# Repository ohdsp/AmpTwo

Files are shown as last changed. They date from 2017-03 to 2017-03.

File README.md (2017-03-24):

# [Open Hardware DSP Platform](http://www.ohdsp.org)
## AmpTwo
### Revision 1.0

---
# README
### Disclaimer
Copyright Paul Janicki 2017

Licensed under the TAPR Open Hardware License (www.tapr.org/OHL)

This documentation is distributed WITHOUT ANY EXPRESS OR IMPLIED WARRANTY, INCLUDING OF MERCHANTABILITY, SATISFACTORY QUALITY AND FITNESS FOR A PARTICULAR PURPOSE.

### What is this repository?

**Quick summary**

This is Open Hardware DSP Platform AmpTwo Module. 

This is a dual independant stereo headphone amplifier with analogue volume control. All 4 channels are fed from different DAC outputs from the ADAU1966 DAC module.

This repository contains the KiCad design files, manufacturing Gerber/drill files, PDF/drawing files, and relevant documenation for this board.

### What is the project folder structure?
Most folder names are self explanatory. Starting from the top level: \
*AmpTwo*
+ *Bill of Materials*  - This contains the bill of materials in CVS, LibreOffice Calc and XML formats
+ *Drawings*  - This contains PDF and SVG outputs of schematic and PCB files
+ *Gerbers* - This contains the PCB Gerbers and drill drawings for manufacture, there is also a zip file ready to send to most manufacturers
+ *KiCad* - This contains the original KiCad schematic and PCB design files
+ *Pick-Place and Stencil* - This contains the pick and place file for automated placement of PCB components and the pasate/stencil layer to make a solder paste stencil 

### How do I get set up?

**Summary of set up**

1. Set your self up a directory on a local disk, something simple will make life easier (eg C:\Electronics on Windows as used here), but anywhere will do just fine.
2. Download the Kicad-Libs from [https://github.com/ohdsp/KiCad-Libs](https://github.com/ohdsp/KiCad-Libs) and place in C:\Electronics\Kicad-Libs (or your chosen folder) 
3. Create a OHDSP subdirectory in C:\Electronics (so C:\Electronics\OHDSP)
3. Download this project to C:\Electronics\OHDSP\AmpTwo
4. Fire up Kicad
5. Open the main project file C:\Electronics\OHDSP\AmpTwo\KiCad\AmpTwo.pro
6. (Optional) Setup Pcbnew component library as below.
7. Do as you wish with the project, just keep it under TAPR Open Hardware License

Make sure your git setup doesn't exclude files used in the project (like .LIB files) or things may go wrong down the line.

**KiCad Library Configuration**

Note that you need to setup a Pcbnew library, but the eeschema libraries should work without any changes if you followed the instructions above.

To setup Pcbnew libraries:

In Pcbnew go to Preferences -> Footprint Libraries Manager. Under Global Libraries tab in the top list check if there is a nickname "MyKiCadLibs-Footprints" (usually at the end of the list). If there is but it points to the wrong place then change the Library Path to point to MyKiCadLibs-Footprints (eg C:\Electronics\KiCad-Libs\MyKiCadLibs-Footprints.pretty) folder for your setup. If this is missing you can use "Append with Wizard", choose "Files on my computer", click next, browse to library location (eg C:\Electronics\KiCad-Libs\MyKiCadLibs-Footprints.pretty) and select the folder MyKiCadLibs-Footprints.pretty, click next, check the Status column states OK and the Format is KiCad (if not re-download the library) and click next, then select "To global library configuration..." and click Finish.

To setup eeschema component libraries:
Either from KiCad project window go to Tools -> Run Library Editor OR under eeschema, go to Tools -> Library Editor. Then Preferences -> Component Libraries.

The top section "Component Library Files" should ideally contain only two libraries, the "power" library that ships with KiCad and "MyKiCadLibs-Lib" available from above. To setup MyKiCadLibs-Lib as a relative path under the "User defined search path" click add. Browse to the location of KiCad-Libs you download above (eg C:\Electronics\KiCad-Libs) and click "Select Folder". Say yes to add a relative path. Under component library files click add, browse to the KiCad-libs again (eg C:\Electronics\KiCad-Libs), select file "MyKiCadLibs-Lib.lib" and click open. MyKiCadLibs-lib should appear in the component library list with no path as it will be using the user defined search path set in the box below.

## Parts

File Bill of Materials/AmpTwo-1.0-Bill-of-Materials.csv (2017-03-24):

Reference | Quantity | Footprint | Value | Description | Voltage | Type | Tolerance | Size | Power
C101 C103 C201 C231 C301 C303 | 6 | CAP-TH-D8mmP3.5mm | 220u | 'Aluminium electrolytic capacitor | '35V | ' | ' | 'Pitch 3.5mm, Diameter 8mm | '
C102 C104 C202 C232 C302 C304 C314 C316 | 8 | SMD-0805 | 100n | 'Ceramic capacitor | '50V | 'X7R | '10% | '0805 | '
C204 C205 C211 C212 C218 C219 C225 C226 | 8 | CAP-TH-D8mmP3.5mm | 100u | 'High quality capacitor, eg Panasonic FC | '35V | ' | ' | 'Pitch 3.5mm, Diameter 8mm | '
C203 C206 C207 C210 C213 C214 C217 C220 C221 C224 C227 C228 | 12 | SMD-0805 | 1n | 'Ceramic capacitor | '50V | 'C0G | '5% | '0805 | '
C208 C209 C215 C216 C222 C223 C229 C230 C309 C310 C321 C322 | 12 | CAP_TH_5mm_W3.5mm | 100n | 'Polyester film capacitor | '63V | 'MKT | '5% | '5mm | '
C305 C306 C307 C308 C317 C318 C319 C320 | 8 | SMD-0805 | 220p | 'Ceramic capacitor | '50V | 'C0G | '5% | '0805 | '
C311 C312 C323 C324 | 4 | CAP-TH-D8mmP3.5mm | 220u | 'High quality capacitor, eg Panasonic FC | '35V | ' | ' | 'Pitch 3.5mm, Diameter 8mm | '
CN301 CN302 | 2 | CON-6.35mm-ACJS-MHDR-FCR11155 | CONN_6.35mm_SW_FCR11155_ACJS-MHDR | '6.35mm PCB Mount Jack - Examples Cliff FCR11155 or AMPHENOL ACJS-MHDR | ' | ' | ' | ' | '
D301 D302 D303 D304 D305 D306 D307 D308 | 8 | DIODE-SOD-123 | 1N4148W | 'Any 1N4148 SOD-123 Diode | ' | ' | ' | ' | '
P101 P102 | 2 | CONN-SCREW-2WAY-7.5mm-7.62mm | CONN_2x1 | '7.5mm or 7.62mm pitch 2 way screw terminal | ' | ' | ' | ' | '
P201 | 1 | CONN_DIL_2X10_BOX_1MM | CONN_02X10 | '2x10 2.54mm pitch box header | ' | ' | ' | ' | '
R202 R208 R211 R218 R221 R228 R231 R238 | 8 | SMD-1206 | 1k3 | 'MELF0204 or 1206 | ' | ' | '1% | '1206 | '250mW
R204 R209 R214 R219 R224 R229 R234 R239 | 8 | SMD-1206 | 1k5 | 'MELF0204 or 1206 | ' | ' | '1% | '1206 | '250mW
R212 R222 R232 R240 | 4 | SMD-1206 | 22k | 'MELF0204 or 1206 | ' | ' | '1% | '1206 | '250mW
R203 R206 R213 R216 R223 R226 R233 R236 | 8 | SMD-1206 | 100k | 'MELF0204 or 1206 | ' | ' | '1% | '1206 | '250mW
R201 R205 R207 R210 R215 R217 R220 R225 R227 R230 R235 R237 | 12 | SMD-1206 | 100 | 'MELF0204 or 1206 | ' | ' | '1% | '1206 | '250mW
R301 R302 R321 R322 R323 R324 R343 R344 | 8 | SMD-1206 | 4k7 | 'MELF0204 or 1206 | ' | ' | '1% | '1206 | '250mW
R303 R304 R305 R306 R313 R314 R315 R316 R317 R318 R325 R326 R327 R328 R335 R336 R337 R338 R339 R340 | 20 | SMD-1206 | 10 | 'MELF0204 or 1206 | ' | ' | '1% | '1206 | '250mW
R307 R308 R309 R310 R311 R312 R319 R320 R329 R330 R331 R332 R333 R334 R341 R342 | 16 | SMD-1206 | 10k | 'MELF0204 or 1206 | ' | ' | '1% | '1206 | '250mW
TR301 TR302 TR305 TR306 | 4 | IC-SOT-223 | BCP56-16 | 'NPN Transistor | '80V | '1A |  |  | '1.5W
TR303 TR304 TR307 TR308 | 4 | IC-SOT-223 | BCP53-16 | 'PNP Transistor | '80V | '1A |  |  | '1.5W
U201 U202 | 2 | IC_SOIC_8 | TLE2082 | Any high quality dual op-amp | '36V
U301 U302 U303 U304 | 4 | IC_SOIC_8 | TLE2081 | Any high quality single op-amp | '36V
VR201 VR202 | 2 | POT_DUAL_16mm_17mm_20mm | 100k | 'Any 16mm, 17mm or 20mm linear dual gang potentiometer | ' | ' | 20% | ' | '

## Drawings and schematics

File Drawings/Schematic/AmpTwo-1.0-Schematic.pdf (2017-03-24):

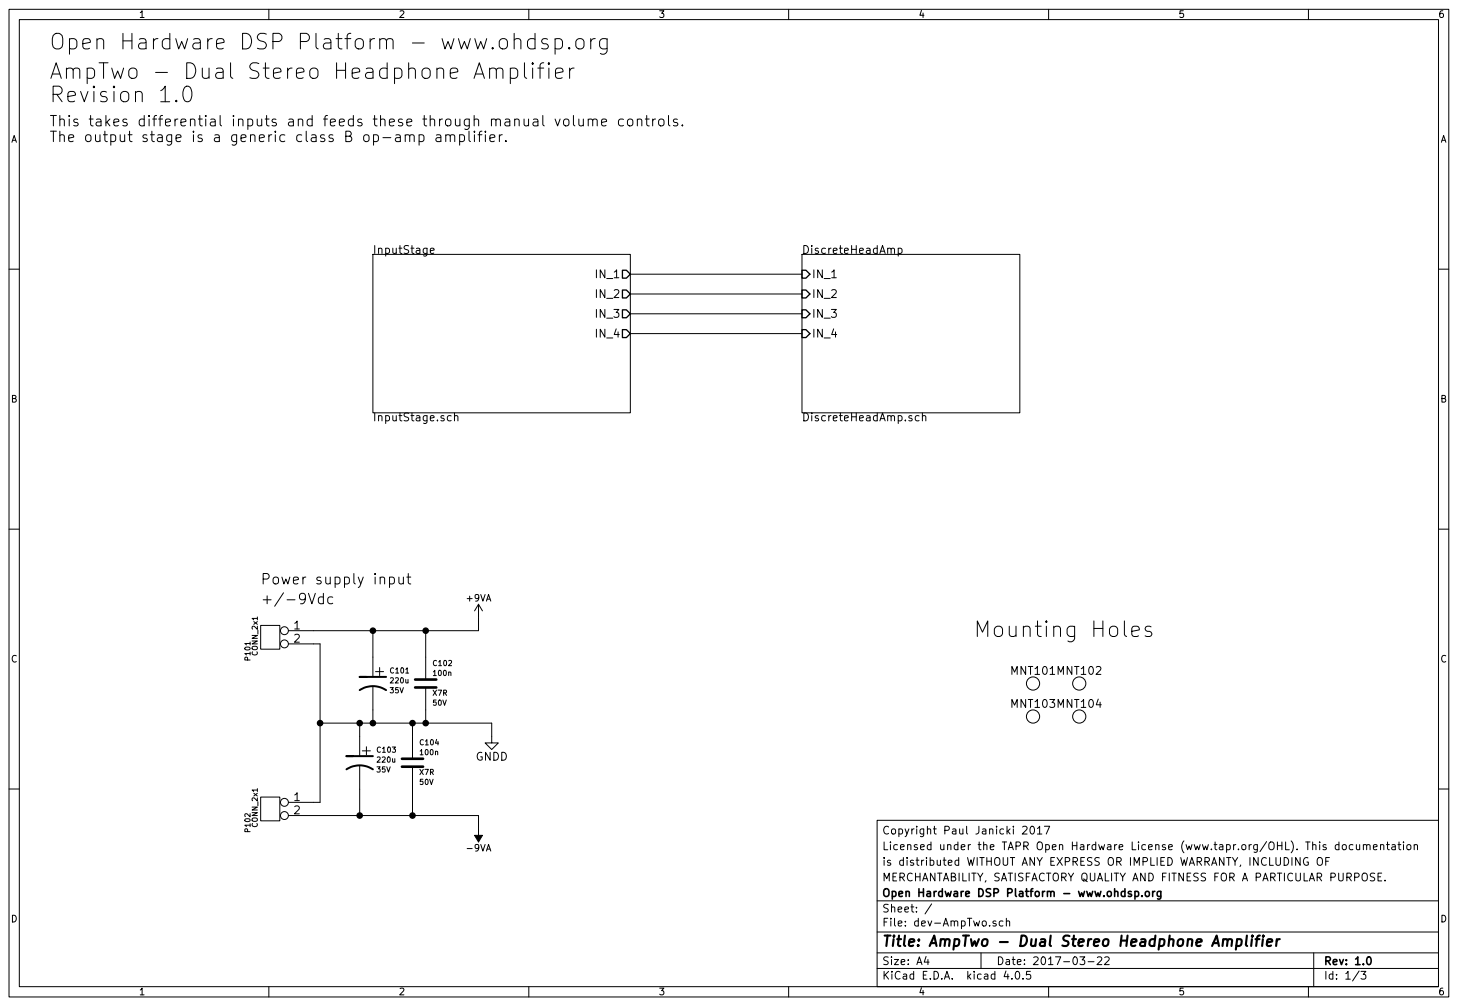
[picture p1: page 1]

Open Hardware DSP Platform - www.ohdsp.org
AmpTwo - Dual Stereo Headphone Amplifier
Revision 1.0
This takes differential inputs and feeds these through manual volume controls.
The output stage is a generic class B op-amp amplifier.

Copyright Paul Janicki 2017
Licensed under the TAPR Open Hardware License (www.tapr.org/OHL). This documentation
is distributed WITHOUT ANY EXPRESS OR IMPLIED WARRANTY, INCLUDING OF
MERCHANTABILITY, SATISFACTORY QUALITY AND FITNESS FOR A PARTICULAR PURPOSE.
File: dev-AmpTwo.sch Sheet: / Open Hardware DSP Platform - www.ohdsp.org

Id: 1/3 Title: AmpTwo - Dual Stereo Headphone Amplifier

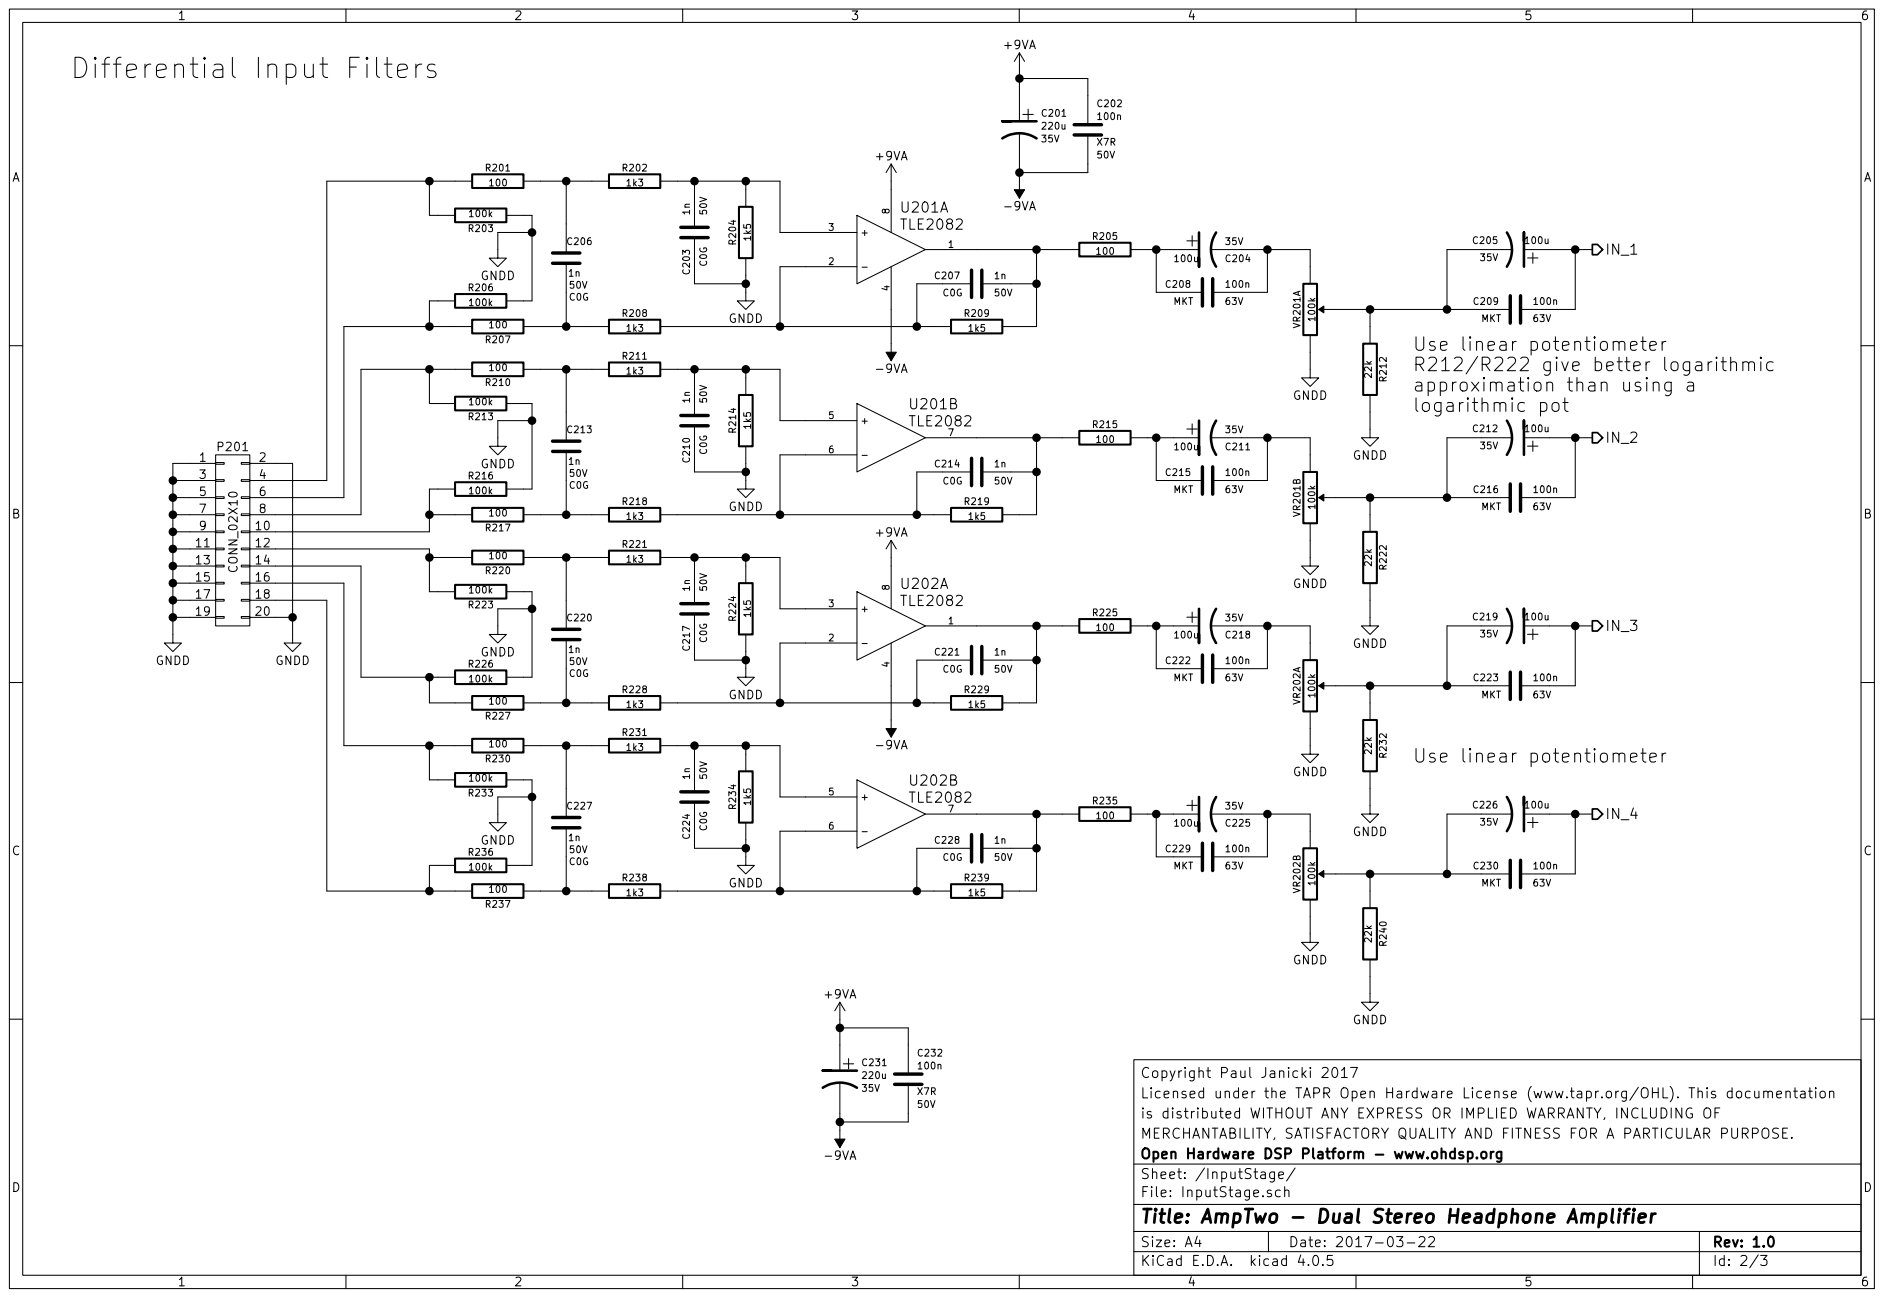
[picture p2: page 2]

11 | 12
13 | 14
15 | 16
17 | 18

Copyright Paul Janicki 2017
Licensed under the TAPR Open Hardware License (www.tapr.org/OHL). This documentation
is distributed WITHOUT ANY EXPRESS OR IMPLIED WARRANTY, INCLUDING OF
MERCHANTABILITY, SATISFACTORY QUALITY AND FITNESS FOR A PARTICULAR PURPOSE.
Open Hardware DSP Platform - www.ohdsp.org
Sheet: /InputStage/
File: InputStage.sch
Id: 2/3 Title: AmpTwo - Dual Stereo Headphone Amplifier

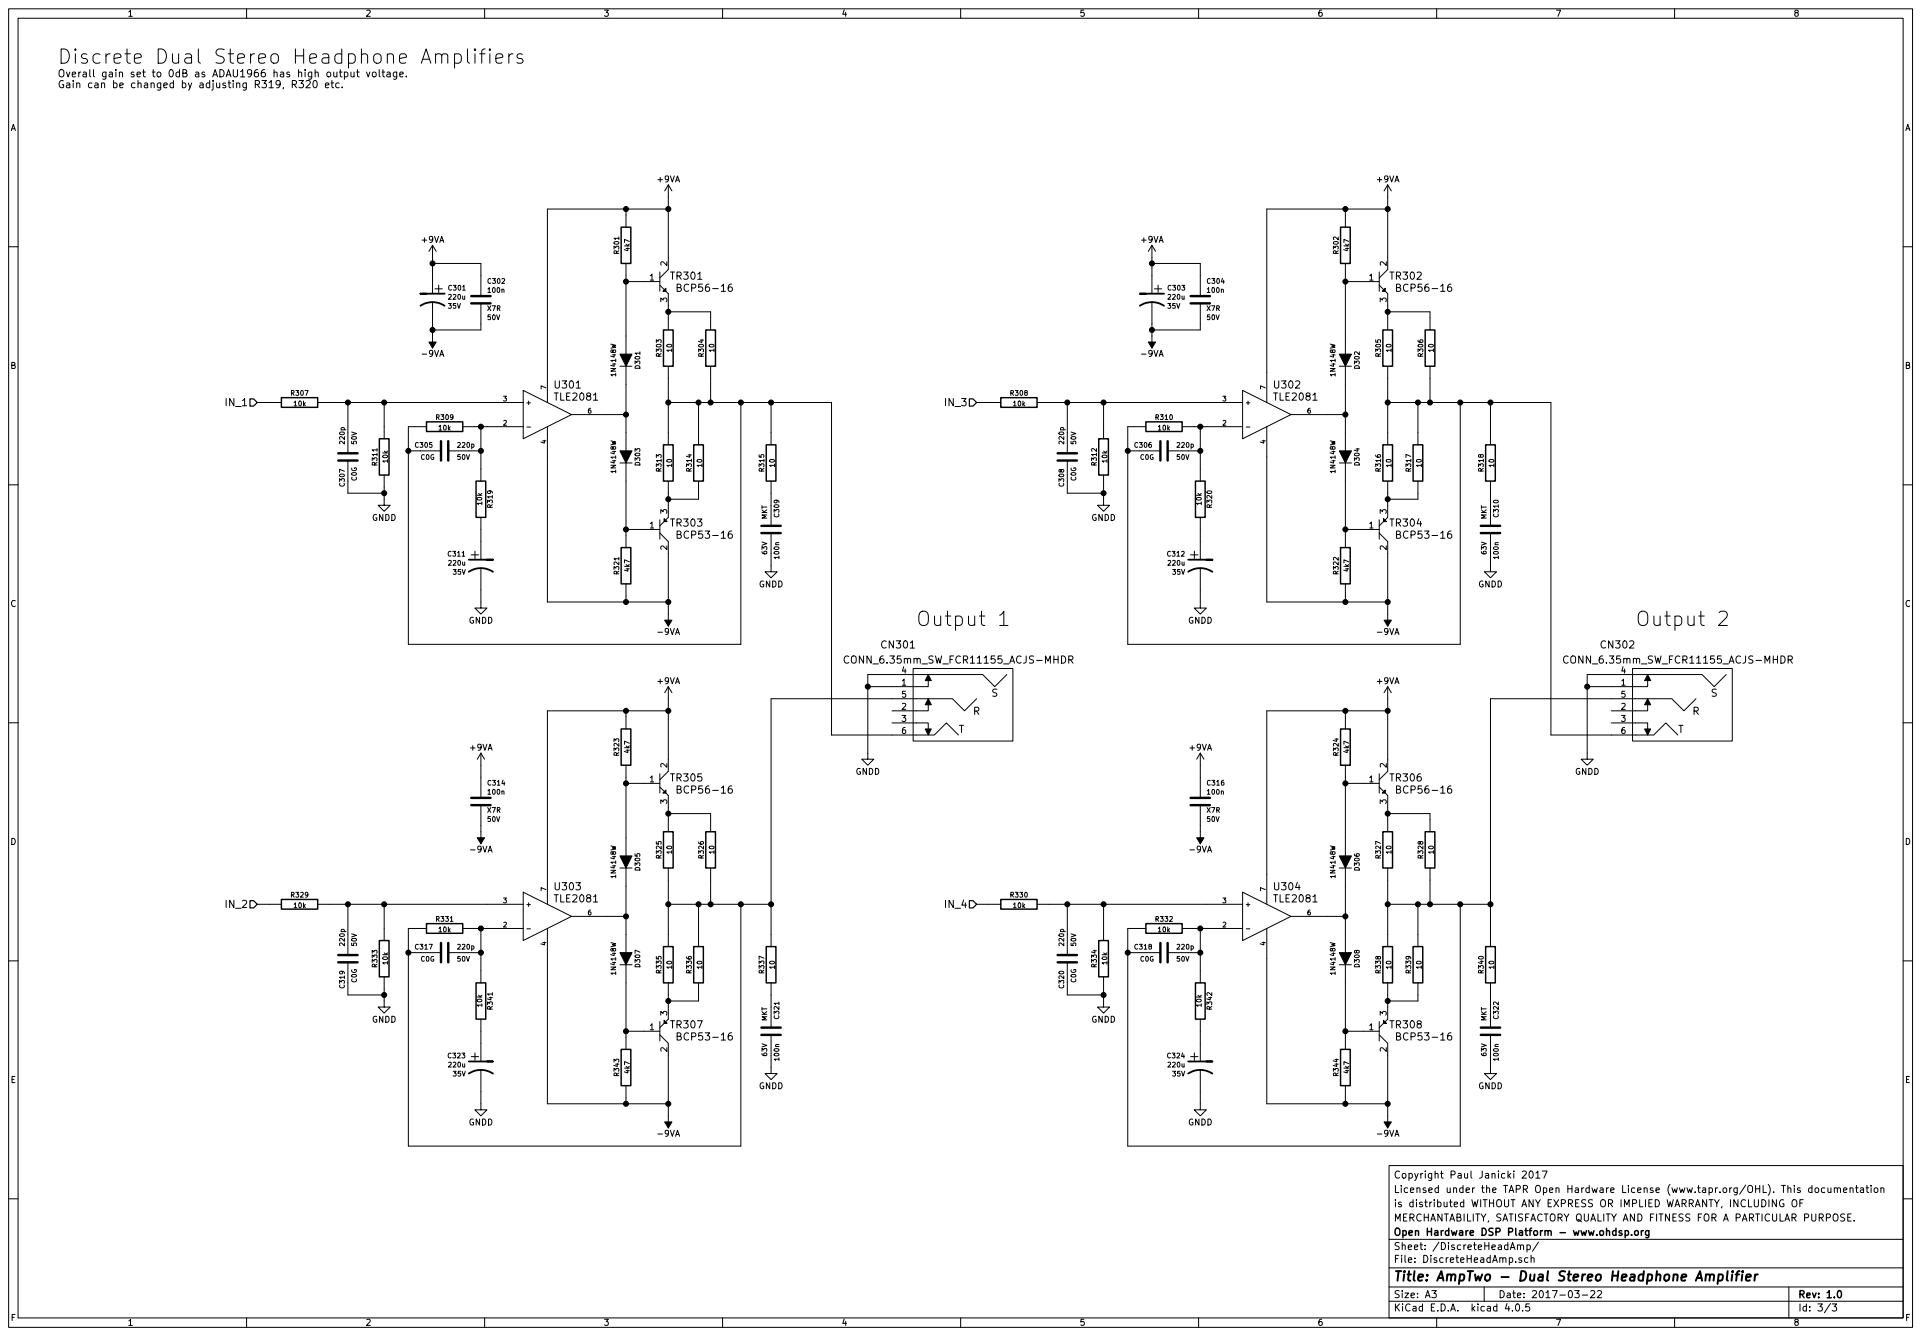
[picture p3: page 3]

Discrete Dual Stereo Headphone Amplifiers

Overall gain set to 0dB as ADAU1966 has high output voltage.
Gain can be changed by adjusting R319, R320 etc.

Copyright Paul Janicki 2017
Licensed under the TAPR Open Hardware License (www.tapr.org/OHL). This documentation
is distributed WITHOUT ANY EXPRESS OR IMPLIED WARRANTY, INCLUDING OF
MERCHANTABILITY, SATISFACTORY QUALITY AND FITNESS FOR A PARTICULAR PURPOSE.
Open Hardware DSP Platform - www.ohdsp.org
Sheet: /DiscreteHeadAmp/
File: DiscreteHeadAmp.sch
Id: 3/3 Title: AmpTwo - Dual Stereo Headphone Amplifier

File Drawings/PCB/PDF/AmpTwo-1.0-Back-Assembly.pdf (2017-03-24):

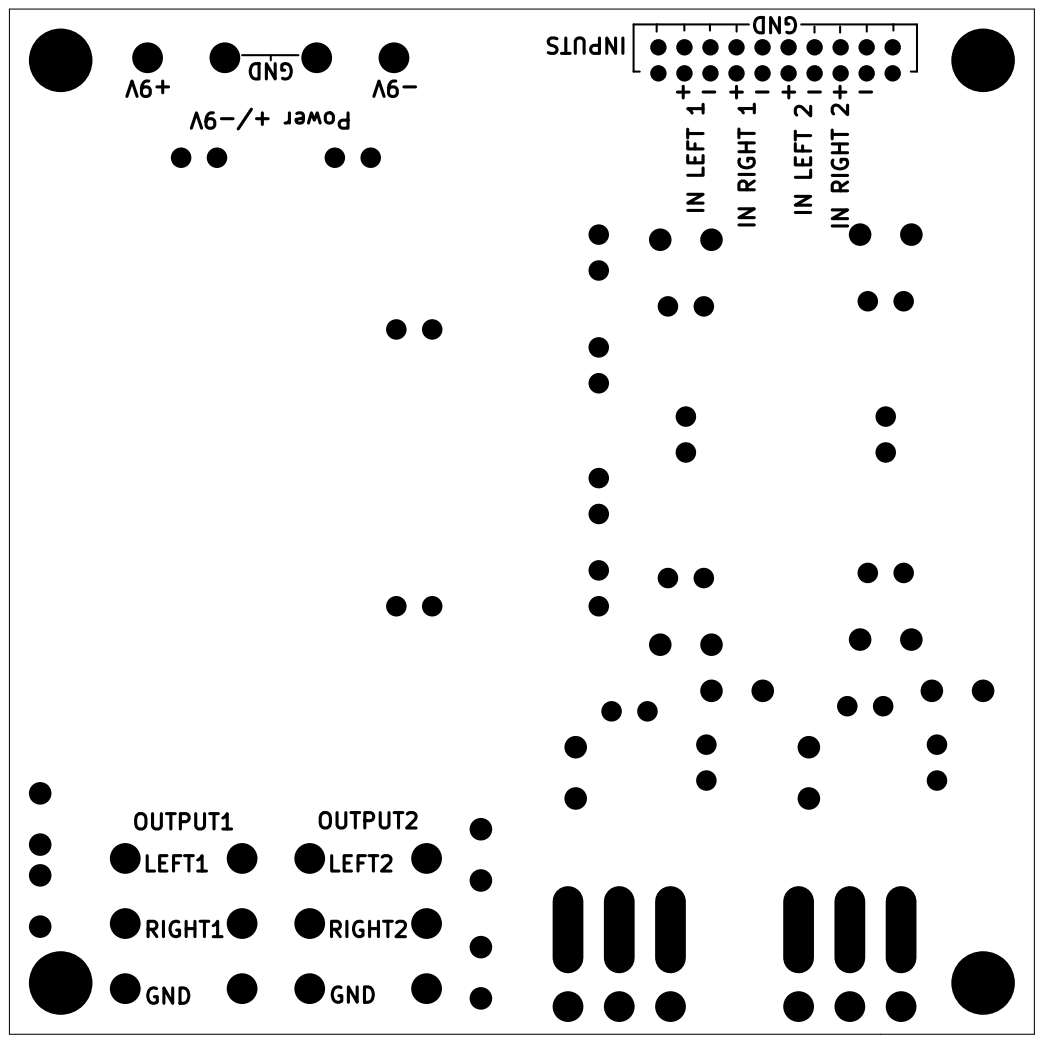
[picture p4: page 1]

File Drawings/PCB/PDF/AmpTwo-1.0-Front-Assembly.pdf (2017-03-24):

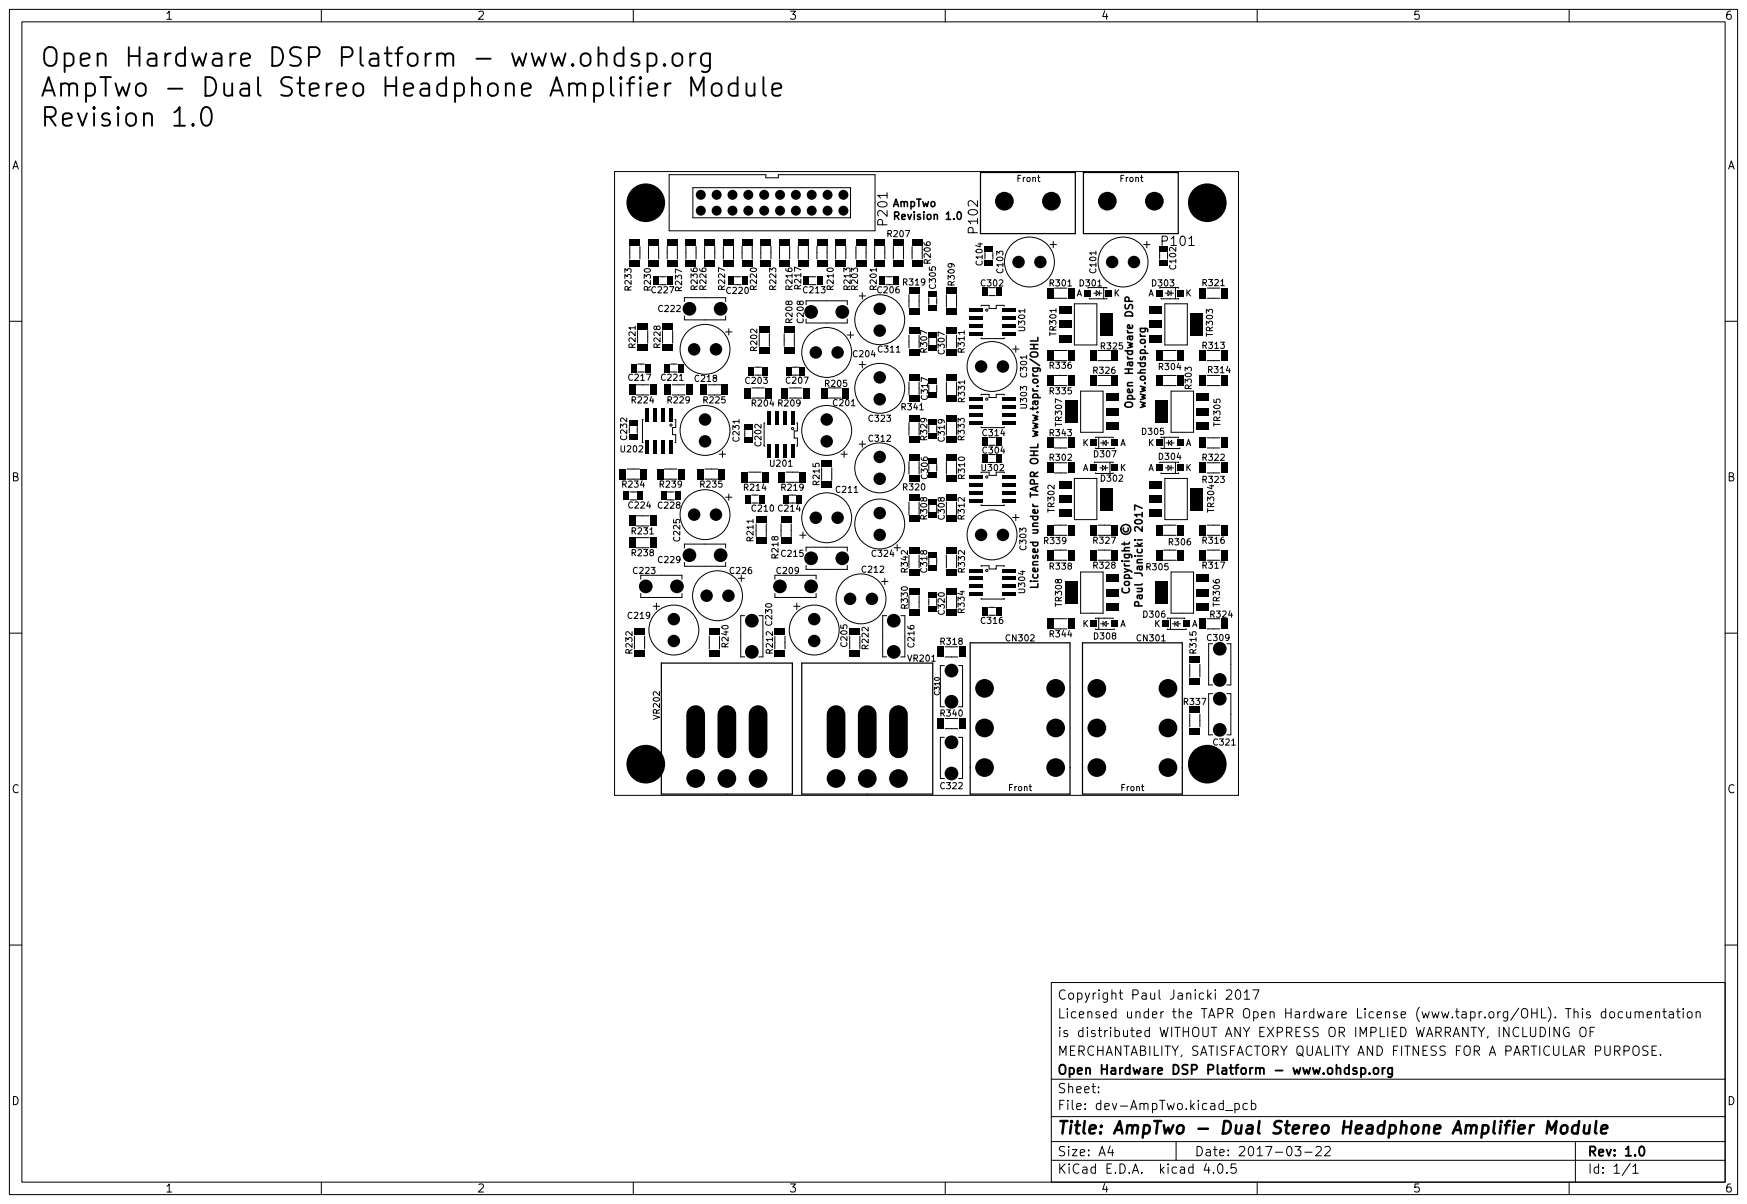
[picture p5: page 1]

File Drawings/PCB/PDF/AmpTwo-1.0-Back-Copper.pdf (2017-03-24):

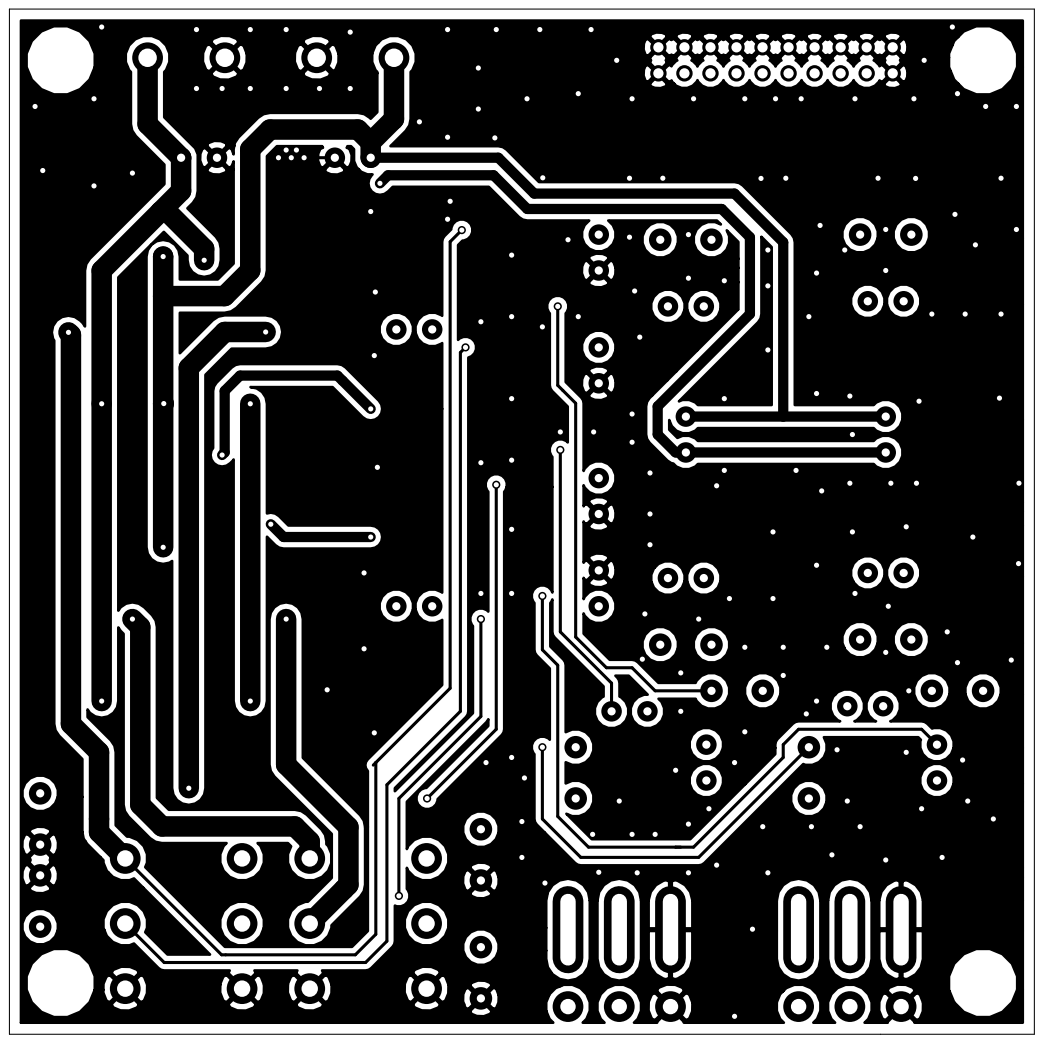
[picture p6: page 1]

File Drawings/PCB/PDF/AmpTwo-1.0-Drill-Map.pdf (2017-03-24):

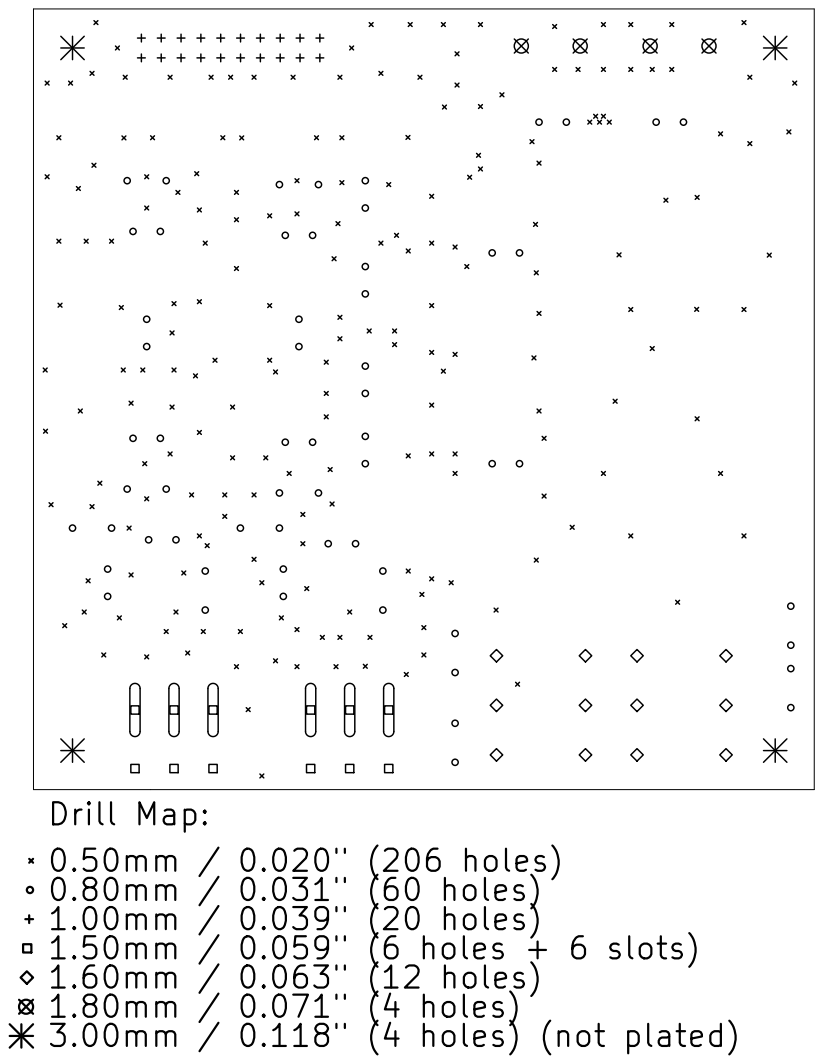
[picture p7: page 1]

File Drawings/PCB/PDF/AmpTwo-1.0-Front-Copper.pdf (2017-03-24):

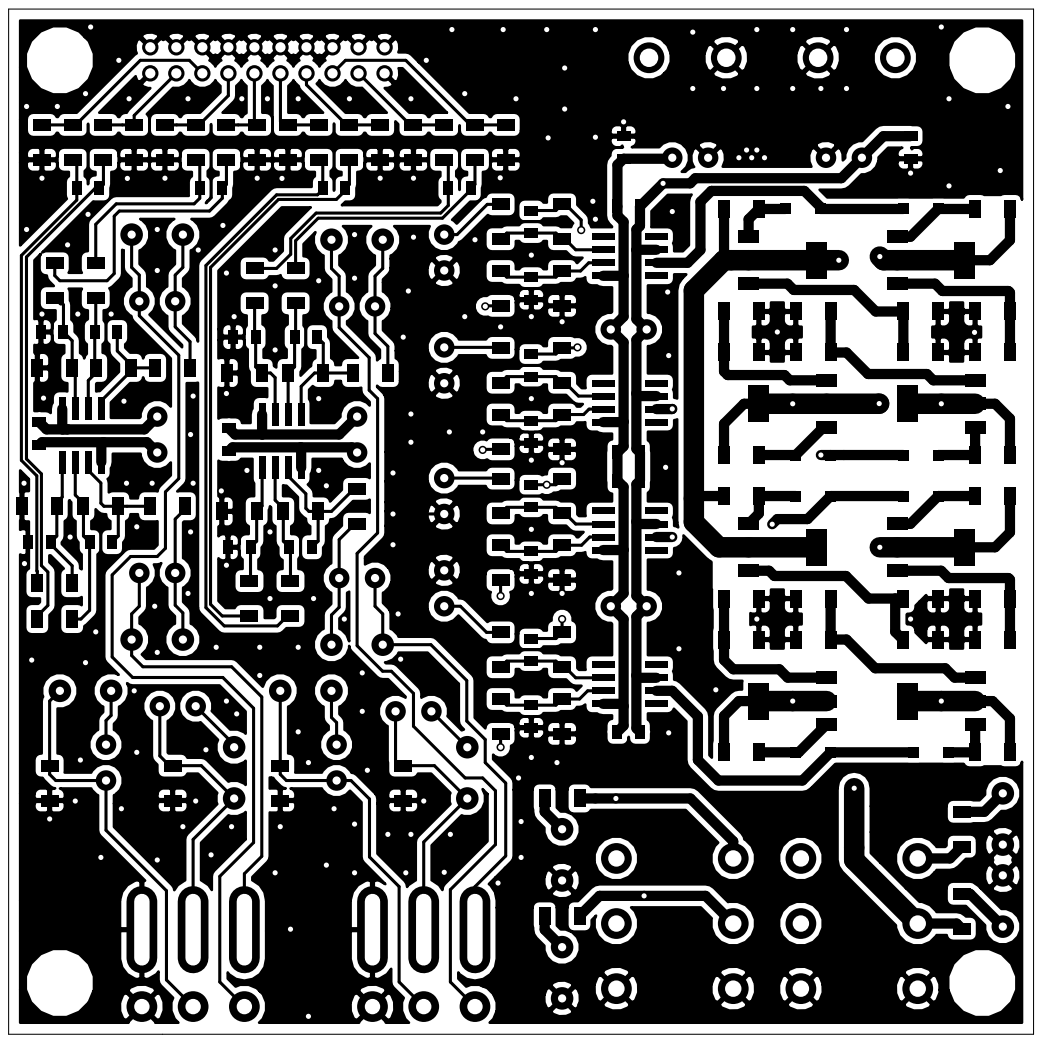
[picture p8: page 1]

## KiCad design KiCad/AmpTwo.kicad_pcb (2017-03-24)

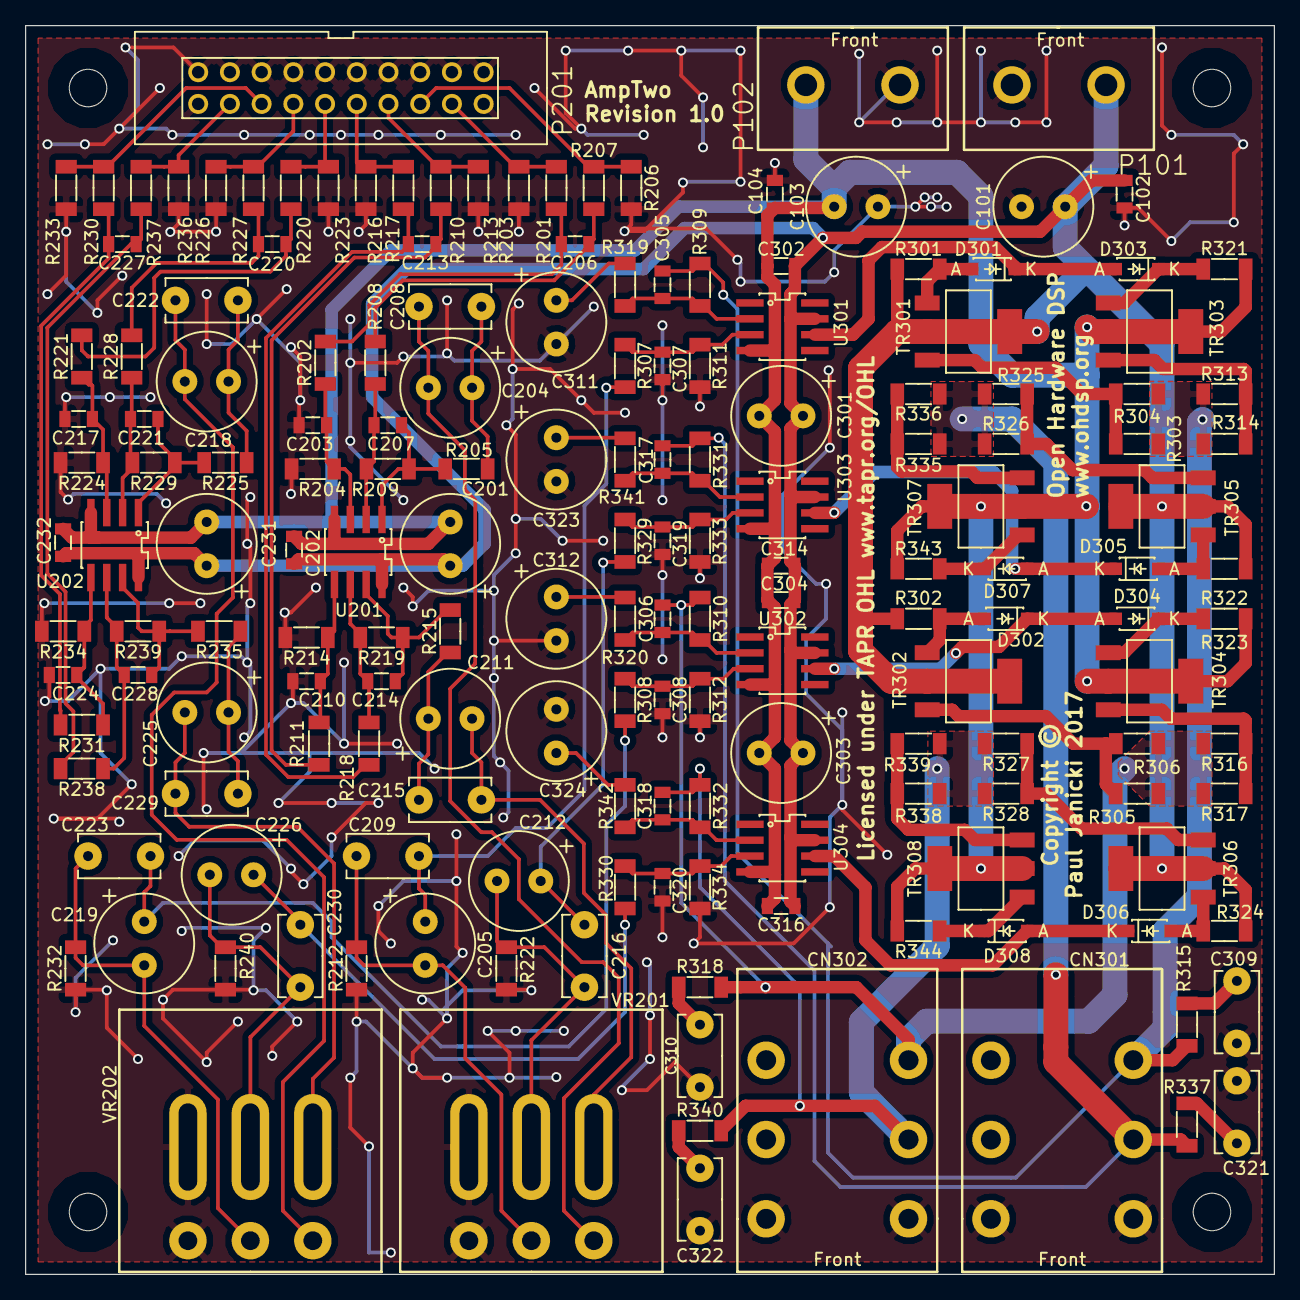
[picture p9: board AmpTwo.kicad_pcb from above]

Board: 2 copper layers, 100.0 x 100.0 mm, 175 parts (0 on the bottom side), 87 nets.

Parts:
C101, C103, C201, C231, C301, C303, C311, C312, C323, C324: 220u; CAP-TH-D8mmP3.5mm
C102, C104, C202, C232, C302, C304, C314, C316: 100n; SMD-0805
C203, C206, C207, C210, C213, C214, C217, C220, C221, C224, C227, C228: 1n; SMD-0805
C204, C205, C211, C212, C218, C219, C225, C226: 100u; CAP-TH-D8mmP3.5mm
C208, C209, C215, C216, C222, C223, C229, C230, C309, C310, C321, C322: 100n; CAP_TH_5mm_W3.5mm
C305, C306, C307, C308, C317, C318, C319, C320: 220p; SMD-0805
CN301, CN302: CONN_6.35mm_SW_FCR11155_ACJS-MHDR; CON-6.35mm-ACJS-MHDR-FCR11155
D301, D302, D303, D304, D305, D306, D307, D308: 1N4148W; DIODE-SOD-123
MNT101, MNT102, MNT103, MNT104: MNT_HOLE; MNT_HOLE_3mm
P101, P102: CONN_2x1; CONN-SCREW-2WAY-7.5mm-7.62mm
P201: CONN_02X10; CONN_DIL_2X10_BOX_1MM
R201, R205, R207, R210, R215, R217, R220, R225, R227, R230, R235, R237: 100; SMD-1206
R202, R208, R211, R218, R221, R228, R231, R238: 1k3; SMD-1206
R203, R206, R213, R216, R223, R226, R233, R236: 100k; SMD-1206
R204, R209, R214, R219, R224, R229, R234, R239: 1k5; SMD-1206
R212, R222, R232, R240: 22k; SMD-1206
R301, R302, R321, R322, R323, R324, R343, R344: 4k7; SMD-1206
R303, R304, R305, R306, R313, R314, R315, R316, R317, R318, R325, R326, R327, R328, R335, R336, R337, R338, R339, R340: 10; SMD-1206
R307, R308, R309, R310, R311, R312, R319, R320, R329, R330, R331, R332, R333, R334, R341, R342: 10k; SMD-1206
TR301, TR302, TR305, TR306: BCP56−16; IC-SOT-223
TR303, TR304, TR307, TR308: BCP53−16; IC-SOT-223
U201, U202: TLE2082; IC_SOIC_8
U301, U302, U303, U304: TLE2081; IC_SOIC_8
VR201, VR202: 100k; POT_DUAL_16mm_17mm_20mm

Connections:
+9VA: C101.1, C102.2, C201.1, C202.2, C231.1, C232.2, C301.1, C302.2, C303.1, C304.2, C314.2, C316.2, P101.1, R301.1, R302.1, R323.1, R324.1, TR301.2, TR302.2, TR305.2, TR306.2, U201.8, U202.8, U301.7, U302.7, U303.7, U304.7
-9VA: C103.2, C104.1, C201.2, C202.1, C231.2, C232.1, C301.2, C302.1, C303.2, C304.1, C314.1, C316.1, P102.2, R321.2, R322.2, R343.2, R344.2, TR303.2, TR304.2, TR307.2, TR308.2, U201.4, U202.4, U301.4, U302.4, U303.4, U304.4
/DiscreteHeadAmp/IN_1: C205.1, C209.1, R307.2
/DiscreteHeadAmp/IN_2: C212.1, C216.1, R329.2
/DiscreteHeadAmp/IN_3: C219.1, C223.1, R308.2
/DiscreteHeadAmp/IN_4: C226.1, C230.1, R330.2
GNDD: C101.2, C102.1, C103.1, C104.2, C203.2, C210.2, C217.2, C224.2, C307.2, C308.2, C309.1, C310.1, C311.2, C312.2, C319.2, C320.2, C321.1, C322.1, C323.2, C324.2, CN301.1, CN301.4, CN302.1, CN302.4, P101.2, P102.1, P201.1, P201.2, P201.3, P201.5, P201.7, P201.9, P201.11, P201.13, P201.15, P201.17, P201.19, P201.20, R203.2, R204.2, R206.2, R212.1, R213.2, R214.2, R216.2, R222.1, R223.2, R224.2, R226.2, R232.1, R233.2, R234.2, R236.2, R240.1, R311.2, R312.2, R333.2, R334.2, VR201.1, VR201.4, VR202.1, VR202.4
unnamed: C203.1, R202.1, R204.1, U201.3
unnamed: C204.1, C208.2, R205.1
unnamed: C204.2, C208.1, VR201.3
unnamed: C205.2, C209.2, R212.2, VR201.2
unnamed: C206.1, R201.1, R202.2
unnamed: C206.2, R207.1, R208.2
unnamed: C207.1, R205.2, R209.1, U201.1
unnamed: C207.2, R208.1, R209.2, U201.2
unnamed: C210.1, R211.1, R214.1, U201.5
unnamed: C211.1, C215.2, R215.1
unnamed: C211.2, C215.1, VR201.6
unnamed: C212.2, C216.2, R222.2, VR201.5
unnamed: C213.1, R210.1, R211.2
unnamed: C213.2, R217.1, R218.2
unnamed: C214.1, R215.2, R219.1, U201.7
unnamed: C214.2, R218.1, R219.2, U201.6
unnamed: C217.1, R221.1, R224.1, U202.3
unnamed: C218.1, C222.2, R225.1
unnamed: C218.2, C222.1, VR202.3
unnamed: C219.2, C223.2, R232.2, VR202.2
unnamed: C220.1, R220.1, R221.2
unnamed: C220.2, R227.1, R228.2
unnamed: C221.1, R225.2, R229.1, U202.1
unnamed: C221.2, R228.1, R229.2, U202.2
unnamed: C224.1, R231.1, R234.1, U202.5
unnamed: C225.1, C229.2, R235.1
unnamed: C225.2, C229.1, VR202.6
unnamed: C226.2, C230.2, R240.2, VR202.5
unnamed: C227.1, R230.1, R231.2
unnamed: C227.2, R237.1, R238.2
unnamed: C228.1, R235.2, R239.1, U202.7
unnamed: C228.2, R238.1, R239.2, U202.6
unnamed: C305.1, R309.2, R319.1, U301.2
unnamed: C305.2, CN301.6, R303.2, R304.2, R309.1, R313.2, R314.2, R315.2
unnamed: C306.1, R310.2, R320.1, U302.2
unnamed: C306.2, CN302.6, R305.2, R306.2, R310.1, R316.2, R317.2, R318.2
unnamed: C307.1, R307.1, R311.1, U301.3
unnamed: C308.1, R308.1, R312.1, U302.3
unnamed: C309.2, R315.1
unnamed: C310.2, R318.1
unnamed: C311.1, R319.2
unnamed: C312.1, R320.2
unnamed: C317.1, R331.2, R341.1, U303.2
unnamed: C317.2, CN301.5, R325.2, R326.2, R331.1, R335.2, R336.2, R337.2
unnamed: C318.1, R332.2, R342.1, U304.2
unnamed: C318.2, CN302.5, R327.2, R328.2, R332.1, R338.2, R339.2, R340.2
unnamed: C319.1, R329.1, R333.1, U303.3
unnamed: C320.1, R330.1, R334.1, U304.3
unnamed: C321.2, R337.1
unnamed: C322.2, R340.1
unnamed: C323.1, R341.2
unnamed: C324.1, R342.2
unnamed: D301.1, R301.2, TR301.1
unnamed: D301.2, D303.1, U301.6
unnamed: D302.1, R302.2, TR302.1
unnamed: D302.2, D304.1, U302.6
unnamed: D303.2, R321.1, TR303.1
unnamed: D304.2, R322.1, TR304.1
unnamed: D305.1, R323.2, TR305.1
unnamed: D305.2, D307.1, U303.6
unnamed: D306.1, R324.2, TR306.1
unnamed: D306.2, D308.1, U304.6
unnamed: D307.2, R343.1, TR307.1
unnamed: D308.2, R344.1, TR308.1
unnamed: P201.4, R201.2, R203.1
unnamed: P201.6, R206.1, R207.2
unnamed: P201.8, R210.2, R213.1
unnamed: P201.10, R216.1, R217.2
unnamed: P201.12, R220.2, R223.1
unnamed: P201.14, R226.1, R227.2
unnamed: P201.16, R230.2, R233.1
unnamed: P201.18, R236.1, R237.2
unnamed: R303.1, R304.1, TR301.3
unnamed: R305.1, R306.1, TR302.3
unnamed: R313.1, R314.1, TR303.3
unnamed: R316.1, R317.1, TR304.3
unnamed: R325.1, R326.1, TR305.3
unnamed: R327.1, R328.1, TR306.3
unnamed: R335.1, R336.1, TR307.3
unnamed: R338.1, R339.1, TR308.3

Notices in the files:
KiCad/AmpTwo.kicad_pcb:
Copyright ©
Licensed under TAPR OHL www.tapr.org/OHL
